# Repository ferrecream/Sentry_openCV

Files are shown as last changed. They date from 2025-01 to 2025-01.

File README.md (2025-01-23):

# Camera Tracking/Manual Sentry

## **Project Overview**
This project is a camera tracking turret that can follow a target and trigger an action (e.g., shoot) when the target is centered. The system is powered by a Raspberry Pi and an Arduino, with 3D-printed components for the turret structure. The Raspberry Pi runs a tracking algorithm using OpenCV, while the Arduino controls the turret’s movement and firing mechanism. There are 2 .py scripts the manual one is the latest verion this one features threading and manual controll And its overall better optimized.
 
---
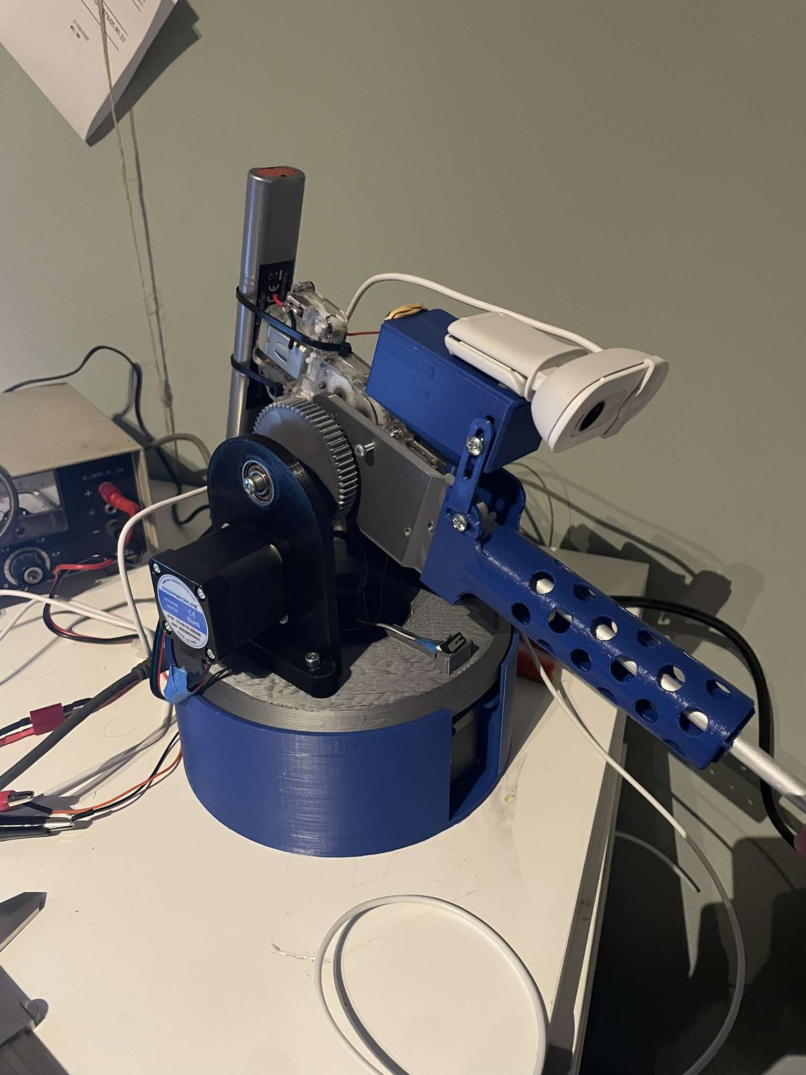
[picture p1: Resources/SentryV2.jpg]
Sentry


https://github.com/user-attachments/assets/e50b6156-1771-4bf7-af76-c94f0d1e761e

## **Features**
- **Real-Time Target Tracking:**
  - Uses OpenCV on a Raspberry Pi to detect and track targets.
  - Sends position corrections to the Arduino via UART.
- **Precision Movement:**
  - Stepper motors ensure smooth and accurate turret movement.
  - Adjustable proportional control for tracking precision.
  - Homing Switch
- **Customizable Shooting Mechanism:**
  - The Arduino triggers a shooting mechanism when the target is centered.
- **3D-Printed Design:**
  - Designed in Fusion 360 and assembled with 3D-printed parts.
- **Remote Control**
   - using Z Q S D to aim manualy on a target.
   - The sentry can be switched from manual mode to tracking mode with ENTER and vise versa.
---

## **Hardware Components**
1. **Turret Structure:**
   - Fully designed in Fusion 360.
   - 3D-printed and manually assembled.
2. **Stepper Motors:**
   - Controls the turret’s pan and tilt movement.
3. **Stepper Drivers:**
   - Connects the stepper motors to the Arduino for precise control.
5. **Relay**
   - The gearbox trigger of the bb-gun is briged using a Relay which is controlled by the Arduino.
4. **Arduino:**
   - Processes UART commands from the Raspberry Pi.
   - Controls the stepper motors and triggers the shooting mechanism.
5. **Raspberry Pi:**
   - Runs the OpenCV-based tracking algorithm.
   - Sends position data and commands to the Arduino.
6. **Camera:**
   - Captures video for real-time tracking.
7. **Shooting Mechanism:**
   - Controlled by the Arduino (e.g., solenoid, servo).
8. **Limit/Homing Switch:**
   - If the Switch is triggerd the Sentry will go to the designated homing position.
---

## **Software Overview**
### **Raspberry Pi**
- **Language:** Python
- **Libraries:**
  - OpenCV for image processing and target tracking.
  - PySerial for UART communication with the Arduino.
- **Key Functionality:**
  - Captures video frames from the camera.
  - Detects and tracks targets using Haar Cascade.
  - Calculates position errors relative to the center of the frame.
  - Sends error data or "shoot" command to the Arduino over UART.

### **Arduino**
- **Language:** C++
- **Libraries:**
  - AccelStepper for stepper motor control.
- **Key Functionality:**
  - Processes position errors received from the Raspberry Pi.
  - Moves steppers to minimize tracking error.
  - Activates the shooting mechanism when the "shoot" command is received.

---

## **Setup Instructions**

### **1. Hardware Assembly**
1. 3D-print the turret components and assemble the structure.
2. Mount the stepper motors and connect them to the stepper drivers.
3. Connect the stepper drivers to the Arduino.
4. Connect the camera to the Raspberry Pi.
5. Power the system (e.g., external power for motors, USB power for Raspberry Pi and Arduino).

### **2. Software Setup**
#### Raspberry Pi:
1. Install required libraries:
   ```bash
   sudo apt update
   sudo apt install python3-opencv python3-serial
   ```
2. Copy the tracking script to the Raspberry Pi.
3. Run the script:
   ```bash
   python3 manualSentryMode.py (or the SentryMode.py PS for absolute noobs do not paste whats in these brackets)
   ```

#### Arduino:
1. Upload the Arduino code using the Arduino IDE.
2. Ensure the UART baud rate matches the Raspberry Pi script (115200).

---

## **Usage**
1. Power on the system.
2. Start the Raspberry Pi tracking script.
3. Place a target within the camera’s field of view.
4. Observe the turret as it tracks the target.
5. When the target is centered, the turret will trigger the shooting mechanism.

---

## **Troubleshooting**
- **Camera Lag:**
  - Reduce the frame resolution and frame rate in the Raspberry Pi script.
- **Stepper Motors Not Responding:**
  - Check the wiring between the Arduino, stepper drivers, and motors.
  - Ensure the correct pins are configured in the Arduino code.
- **Inaccurate Tracking:**
  - Adjust the proportional control parameter (`kp`) in the Arduino code.
- **No Shooting Trigger:**
  - Verify that the Raspberry Pi sends the "shoot" command when the target is centered.

---

## **Future Enhancements**
- Add a web interface to monitor and control the turret remotely.
- Implement more advanced tracking algorithms (e.g., YOLO or Deep Learning models).
- Integrate additional sensors for enhanced precision and safety.

## License

This project is open-source and available under the MIT License.

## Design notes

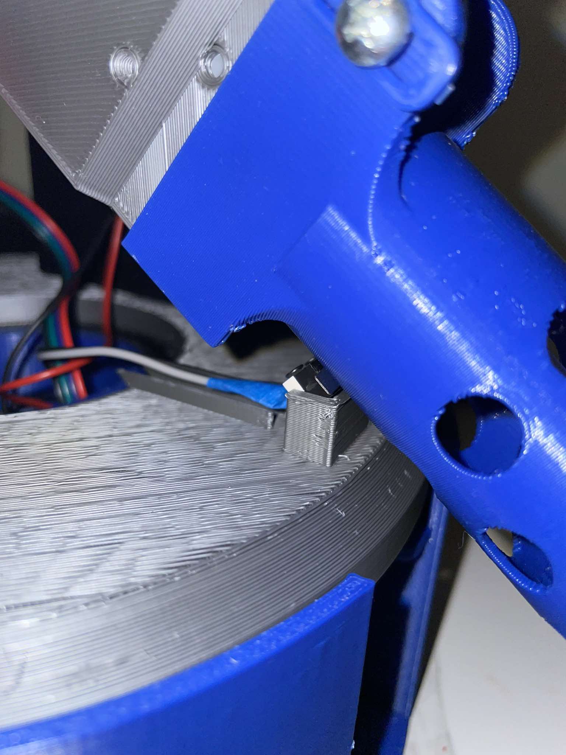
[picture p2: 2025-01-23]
Resources/LimitSwitch.jpg

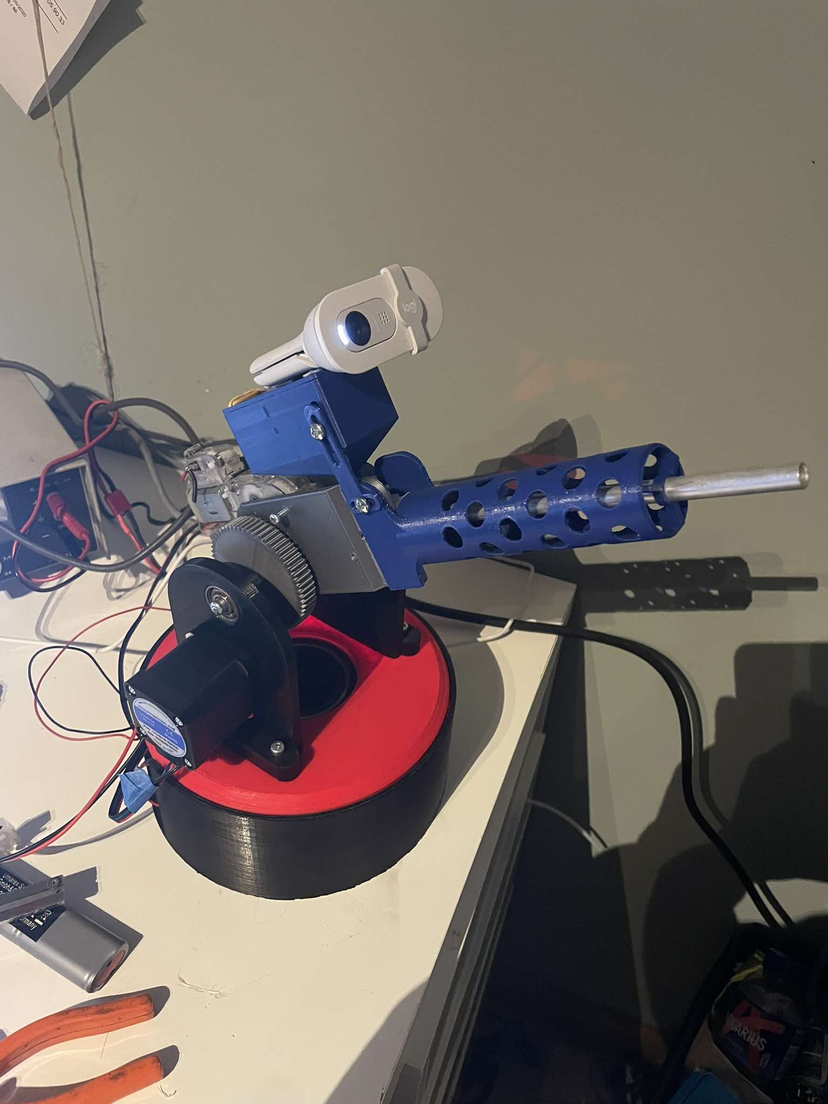
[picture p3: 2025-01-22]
Resources/SentryPic.jpg

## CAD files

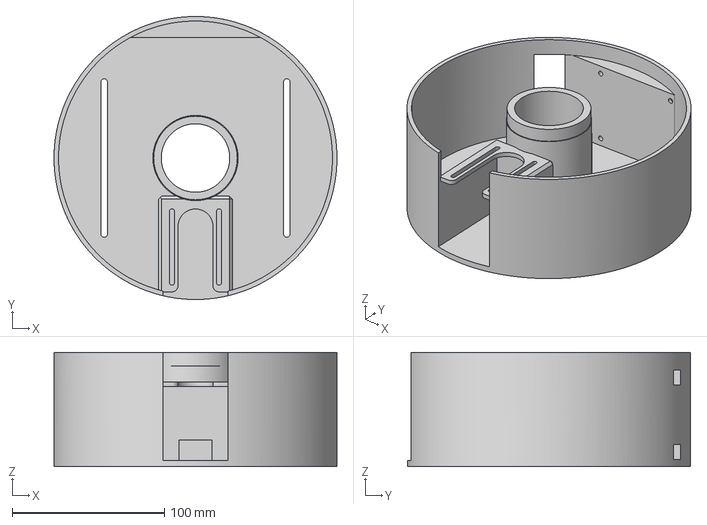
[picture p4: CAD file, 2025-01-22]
Design_Files/SentryBaseV2.3mf
186.0 x 186.0 x 75.0 mm

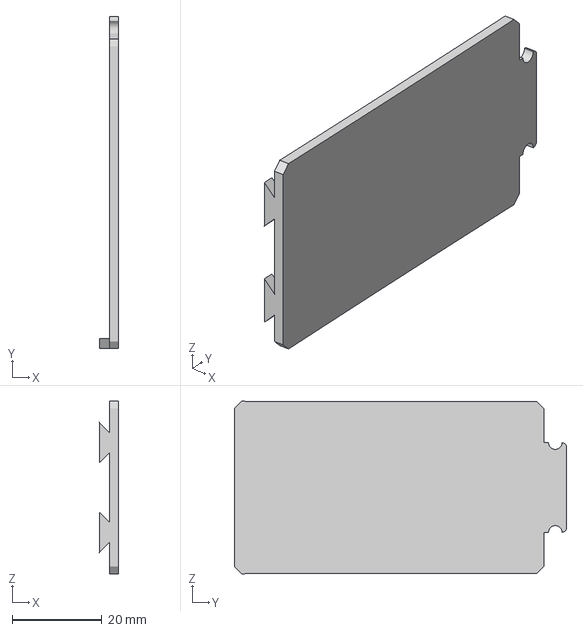
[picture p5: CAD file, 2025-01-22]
Design_Files/bb_hopperCover.3mf
4.30 x 74.1 x 38.5 mm

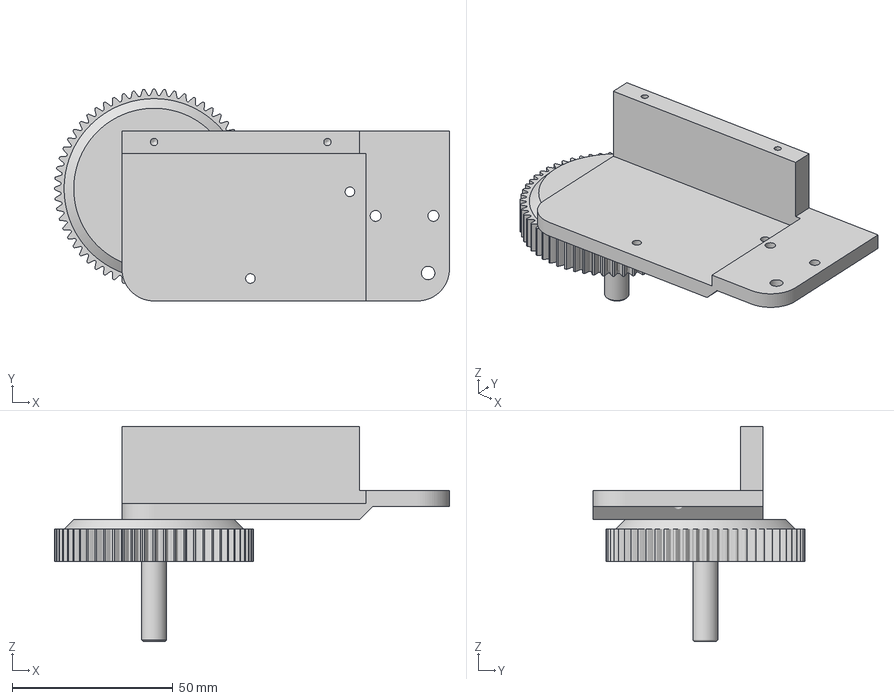
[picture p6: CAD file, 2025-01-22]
Design_Files/gear_turretron.3mf
123.0 x 66.0 x 67.0 mm

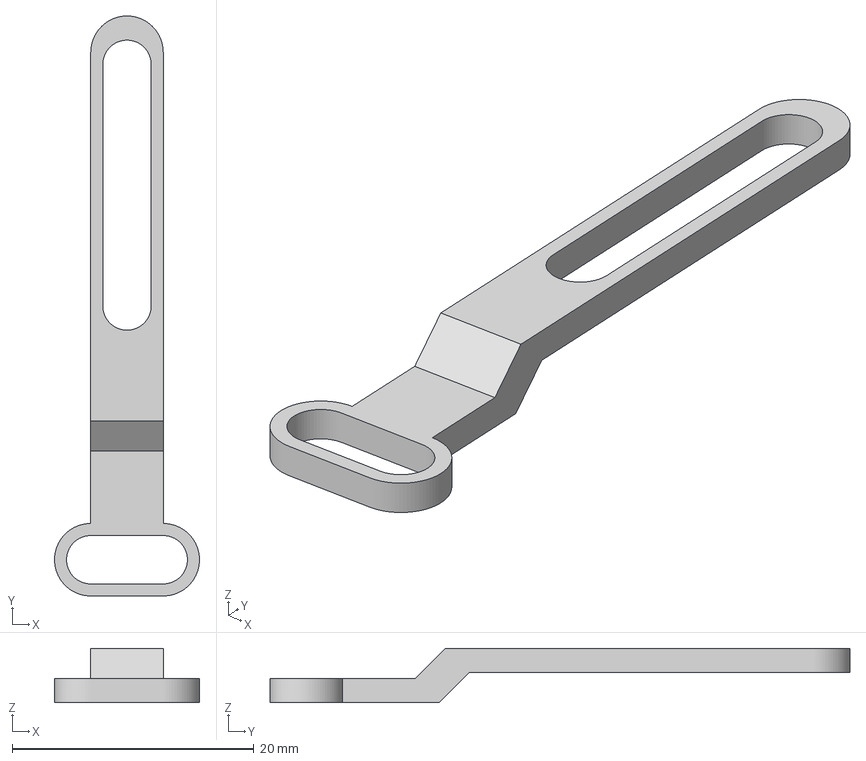
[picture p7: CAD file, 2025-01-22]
Design_Files/Connector.3mf
12.0 x 48.0 x 4.50 mm

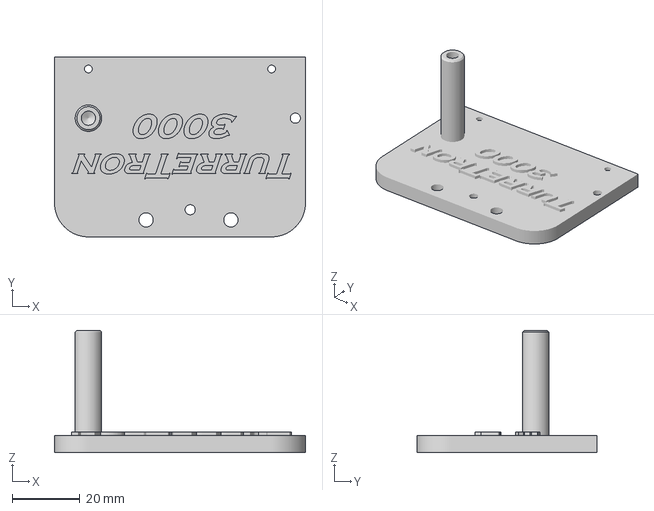
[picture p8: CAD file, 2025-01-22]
Design_Files/Turretron.3mf
74.0 x 53.0 x 36.0 mm

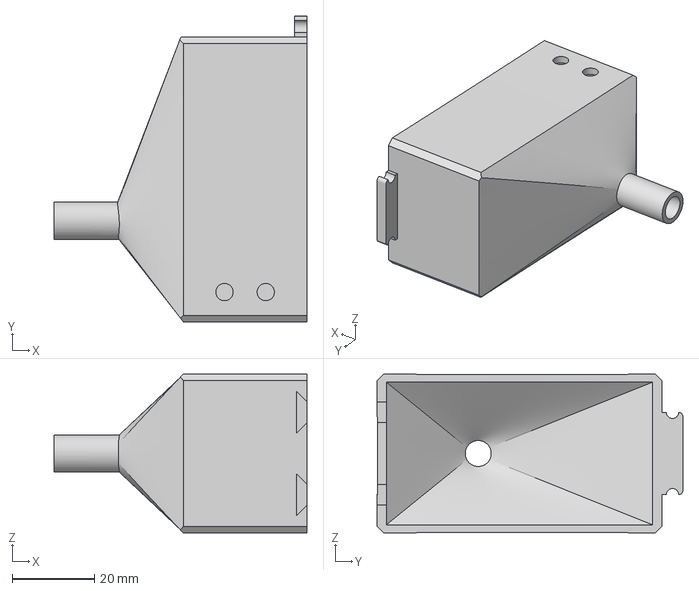
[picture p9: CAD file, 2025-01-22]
Design_Files/bb_hopper.3mf
61.4 x 74.1 x 38.5 mm

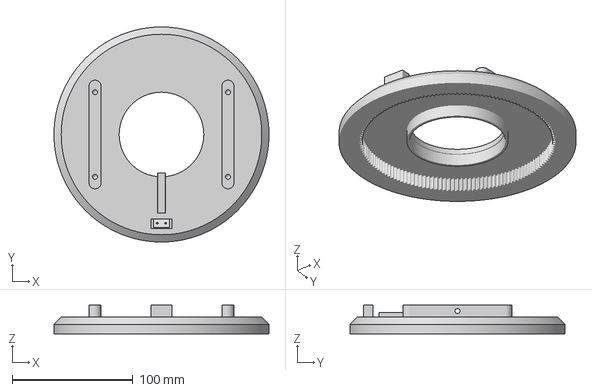
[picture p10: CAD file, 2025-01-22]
Design_Files/SentryBaseRotation.3mf
178.0 x 178.0 x 24.0 mm

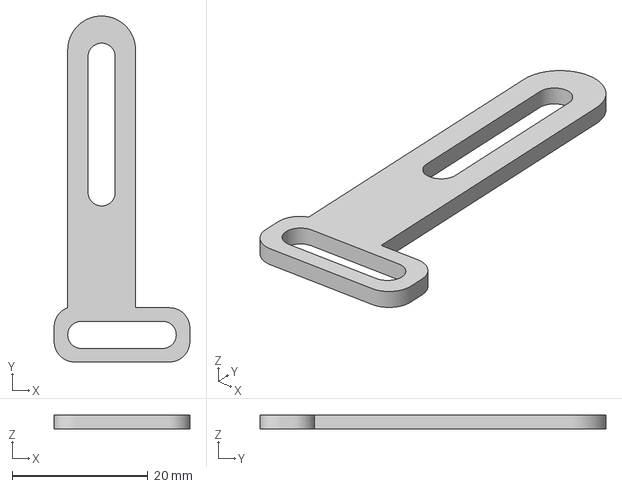
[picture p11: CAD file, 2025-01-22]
Design_Files/flatter.3mf
20.0 x 51.0 x 2.00 mm

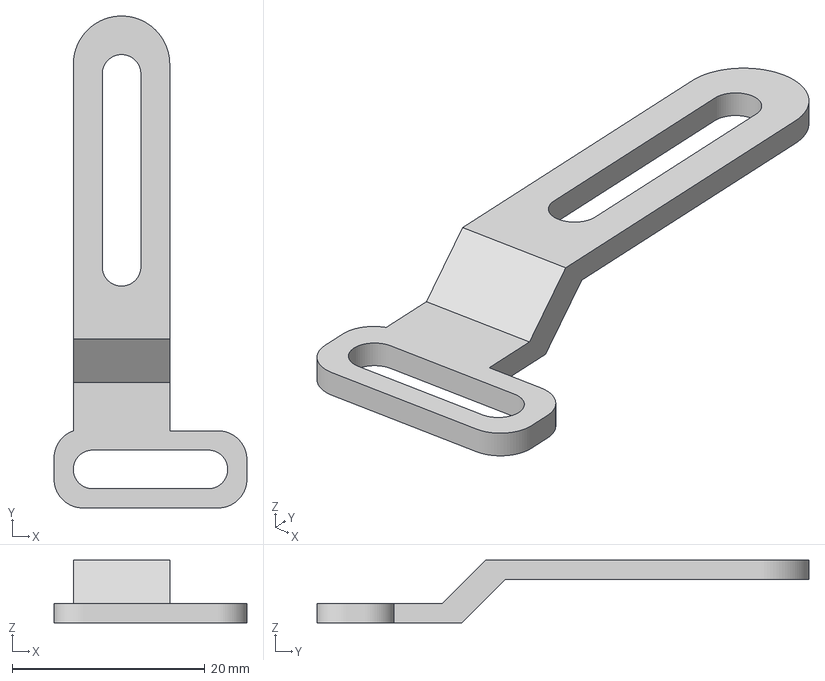
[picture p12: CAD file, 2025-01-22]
Design_Files/connector_test.3mf
20.0 x 51.0 x 6.50 mm

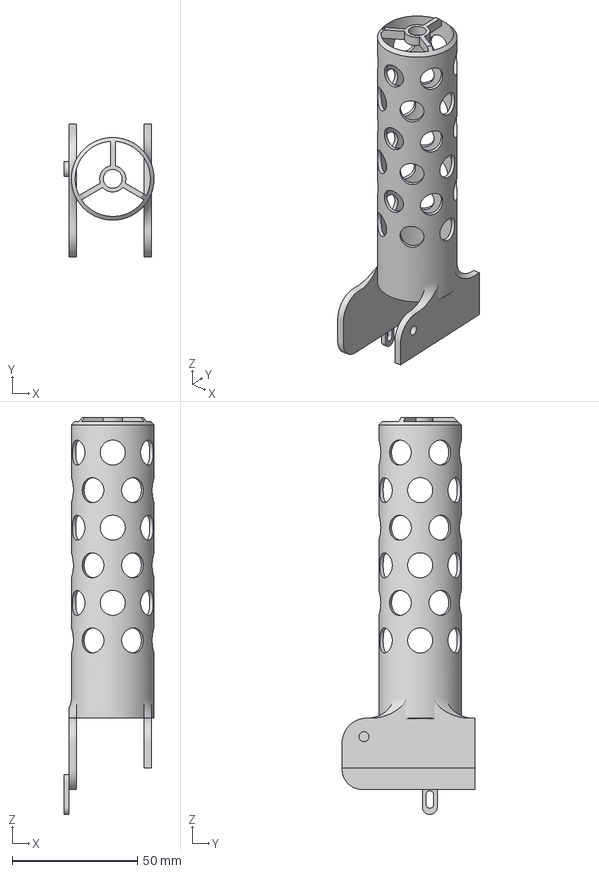
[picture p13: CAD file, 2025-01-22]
Design_Files/barrel_ecstatic.3mf
36.0 x 53.0 x 158.5 mm

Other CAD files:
Design_Files/base_actuatorgear v3.f3d
Design_Files/bb_hopper v2.f3d
Design_Files/carier_gearbox_turret v5.f3d
Design_Files/turret_base v4.f3d
Design_Files/turretbase_rotation v8.f3d

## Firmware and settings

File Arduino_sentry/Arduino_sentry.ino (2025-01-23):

#include <AccelStepper.h>

#define dirPin1 2
#define stepPin1 3
#define dirPin2 4
#define stepPin2 5
#define motorInterfaceType 1
#define shootPin 6
#define homePin 7

AccelStepper stepper1(motorInterfaceType, stepPin1, dirPin1);
AccelStepper stepper2(motorInterfaceType, stepPin2, dirPin2);

float kp = 0.2;
int deadZone = 5;
bool homing = false; // Flag to indicate if homing is active

void setup() {
  Serial.begin(115200);

  // Configure max speed and acceleration
  stepper1.setMaxSpeed(4000); // Increased speed
  stepper1.setAcceleration(20000); // Increased acceleration
  stepper2.setMaxSpeed(4000);
  stepper2.setAcceleration(20000);

  pinMode(homePin, INPUT_PULLUP);
  pinMode(shootPin, OUTPUT);
}

void loop() {
  // Non-blocking homing
  if (digitalRead(homePin) == LOW && !homing) {
    stepper1.move(-1800); // Move to the home position
    homing = true;
  }

  if (homing) {
    stepper1.run(); // Run the homing move
    stepper2.run(); // Keep stepper 2 active (even if stationary)
    if (stepper1.distanceToGo() == 0) {
      homing = false; // Homing completed
    }
    return; // Skip other operations while homing
  }

  // Handle serial input
  if (Serial.available() > 0) {
    String input = Serial.readStringUntil('\n');
    input.trim();

    if (input == "shoot") {
      digitalWrite(shootPin, HIGH);
      delay(80);
      digitalWrite(shootPin, LOW);
    } else {
      int commaIndex = input.indexOf(',');
      if (commaIndex > 0) {
        int xError = input.substring(0, commaIndex).toInt();
        int yError = input.substring(commaIndex + 1).toInt();

        // Only move if the error is outside the dead zone
        if (abs(xError) > deadZone) {
          int xMove = kp * xError * 2; // Scale for faster movement
          stepper1.moveTo(stepper1.currentPosition() + xMove);
        }
        if (abs(yError) > deadZone) {
          int yMove = kp * yError * 2; // Scale for faster movement
          stepper2.moveTo(stepper2.currentPosition() + yMove);
        }
      }
    }
  }

  // Run steppers continuously (non-blocking)
  stepper1.run();
  stepper2.run();
}

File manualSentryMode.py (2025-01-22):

import cv2
import serial
import time
from pynput import keyboard
from threading import Thread

# Initialize serial communication with Arduino
ser = serial.Serial("/dev/ttyUSB0", 115200, timeout=1)
ser.setDTR(False)
time.sleep(1)
ser.flushInput()
ser.setDTR(True)
time.sleep(2)

# Load Haar Cascade for face detection
body_cascade = cv2.CascadeClassifier(cv2.data.haarcascades + 'haarcascade_frontalface_default.xml')

# Variables
manual_mode = False
keys_pressed = set()
frame = None
running = True


class CameraThread:
    """Threaded camera class for continuous frame capture."""
    def __init__(self):
        self.capture = cv2.VideoCapture(0)
        self.capture.set(cv2.CAP_PROP_FRAME_WIDTH, 320)
        self.capture.set(cv2.CAP_PROP_FRAME_HEIGHT, 240)
        self.capture.set(cv2.CAP_PROP_FPS, 15)
        self.frame = None
        self.running = True
        self.thread = Thread(target=self.update, daemon=True)

    def start(self):
        """Start the thread."""
        self.thread.start()

    def update(self):
        """Continuously capture frames."""
        while self.running:
            ret, frame = self.capture.read()
            if ret:
                self.frame = frame

    def read(self):
        """Get the latest frame."""
        return self.frame

    def stop(self):
        """Stop the thread."""
        self.running = False
        self.thread.join()
        self.capture.release()


def track_body(center_x, center_y, frame_width, frame_height):
    """Track the target and send commands to the Arduino."""
    tolerance = 20  # pixels
    x_error = center_x - (frame_width // 2)
    y_error = center_y - (frame_height // 2)

    x_error = x_error * 2.5 #stepper speed adsjusment
    y_error = y_error * 7.5 
    
    if abs(x_error) <= tolerance and abs(y_error) <= tolerance:
        ser.write(b"shoot\n")
    else:
        command = f"{y_error},{x_error}\n"
        ser.write(command.encode('utf-8'))


def manual_control():
    """Send manual control commands based on key presses."""
    if 'q' in keys_pressed:
        ser.write(b"0,-300\n")  # Move up
    if 'd' in keys_pressed:
        ser.write(b"0,300\n")  # Move down
    if 'z' in keys_pressed:
        ser.write(b"-100,0\n")  # Move left
    if 's' in keys_pressed:
        ser.write(b"100,0\n")  # Move right
    if 'space' in keys_pressed:
        ser.write(b"shoot\n")  # Shoot


def on_press(key):
    """Handle key press events."""
    global manual_mode
    try:
        if key.char in ['z', 'q', 's', 'd', ' ']:
            keys_pressed.add(key.char)
    except AttributeError:
        if key == keyboard.Key.enter:
            manual_mode = not manual_mode
            print(f"Manual mode {'activated' if manual_mode else 'deactivated'}")
        elif key == keyboard.Key.esc:
            global running
            running = False
            return False


def on_release(key):
    """Handle key release events."""
    try:
        if key.char in ['z', 'q', 's', 'd', ' ']:
            keys_pressed.discard(key.char)
    except AttributeError:
        pass


# Initialize threaded camera and keyboard listener
camera = CameraThread()
listener = keyboard.Listener(on_press=on_press, on_release=on_release)

try:
    camera.start()
    listener.start()

    while running:
        frame = camera.read()
        if frame is None:
            continue

        if manual_mode:
            manual_control()
        else:
            # Tracking mode
            gray = cv2.cvtColor(frame, cv2.COLOR_BGR2GRAY)
            faces = body_cascade.detectMultiScale(gray, 1.1, 3, minSize=(30, 30))

            for (x, y, w, h) in faces:
                cv2.rectangle(frame, (x, y), (x + w, y + h), (255, 0, 0), 2)
                center_x = x + w // 2
                center_y = y + h // 2
                track_body(center_x, center_y, frame.shape[1], frame.shape[0])

        cv2.imshow('Frame', frame)

        if cv2.waitKey(1) & 0xFF == ord('q'):
            running = False

finally:
    camera.stop()
    listener.stop()
    cv2.destroyAllWindows()

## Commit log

2025-01-16 readme etc
    [base_actuatorgear v3.f3d, bb_hopper v2.f3d, carier_gearbox_turret v5.f3d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]
2025-01-23 LimitSwitch/homing added
